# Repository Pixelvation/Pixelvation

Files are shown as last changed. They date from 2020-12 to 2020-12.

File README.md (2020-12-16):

**Pixelvation enables people to create high-quality LED art using open source tools**

This GitHub repository is the current home of Pixelvation and will be updated whenever there's some significant new development.  To get notified on significant new developments, set up an alert on new releases here, or follow [@PixelvationRGB on Twitter](https://twitter.com/PixelvationRgb).

I'll set up a forum or Discord server at some point, but for now, feel free to open a GitHub Issue, or post to [SmartMatrix Community](https://community.pixelmatix.com) if you have any questions or want to discuss anything.

## Open Source Early

I've released several open source products, where the open source files were published after the product was designed, manufactured, and at a distributor ready to purchase.  With my [latest crowdfunded product](https://www.crowdsupply.com/pixelmatix/smartled-shield-for-teensy-4) I realized how much time I had spent on marketing and logistics while prepping for and running the campaign - work I really dislike - relative to the creative and technical work that I really enjoy.  I also really enjoy sharing my projects and collaborating with other people, but releasing the product through a crowdfunding campaign delayed the start of fully sharing my project details and collaborating with other people by months.

With Pixelvation, I'm trying a new approach to sharing my projects: releasing projects as open source early on - well before I even have plans to release a project as a product - and making it easy for people to source the hardware themselves.  I'm designing my projects around components that are available from [JLCPCB's SMT Library](https://jlcpcb.com/parts) whenever possible, so if you want to try one of the hardware designs you just place an order with JLCPCB for 5+ pieces of assembled PCBs, and they'll be manufactured and shipped for a very reasonable price in under a week.

I'm releasing work-in-progress designs under a CC BY-NC-SA license.  Usually I don't release my designs with a "-NC" Non-Commercial license, and after the design is further along and ready for sale I'll change the license to CC BY-SA.  I'm conflicted about this and may change my mind later as designs released "-NC" aren't truly open source, but for now I'm being conservative and keeping the "-NC".

## Pixelvation Engine

The first tool in development now is the Pixelvation Engine, a small board dedicated to receiving a single stream of LED data via serial, and driving a lot of LEDs with that data.  The Engine will support driving HUB75 panels, or addressable LEDs.

Pixelvation Engine Overhead View

As input, Pixelvation Engine accepts APA102 data at up to 5MHz, with 1-bit serial (like an APA102 LED), or up to 8-bit parallel.  The 1-bit serial input and CLK are buffered to accept up to 5V signals, but the remaining 7-bits parallel data must be driven at 3.3V only.

Pixelvation Engine has 16 outputs buffered to 5V levels, and an extra 3.3V output.  The outputs are arranged around the pinout of a HUB75 panel, so the board can be plugged into a HUB75 panel directly.  To instead drive up to 16 channels of addressable LEDs, Pixelvation Engine needs to be plugged into a simple breakout board.  Generic breakout boards will be designed and released in the future, but you can also design your own project-specific breakout board with space for the Pixelvation Engine, and the form factor and LED connectors your project actually needs.

Pixelvation Engine is based around the ESP32, which has enough RAM, CPU power, and DMA functionality to deal with a lot of LED data, and some unique I2S peripherals that allow for receiving a fast stream of serial or parallel LED data as input, and setting up another stream of parallel LED data as output.

To program Pixelvation Engine you need a USB-Serial adapter.  This functionality was purposely left off the board to save space and cost, and ideally these features are only needed when setting up a project.  The programming pins on the input side were designed around the ESP-01 pinout, so cheap ESP-01 programmers can be used.  Specifically [this ESP-01 programmer](https://www.amazon.com/ESP-01S-Programmer-Adapter-Wireless-4-5-5-5V/dp/B07V556Q82) ([cheaper on Aliexpress](https://www.aliexpress.com/item/32882742790.html))  has the most functionality and is the easiest to use on its own, is widely available, and with a couple jumper wires added becomes even more functional.

Pixelvation Engine Programmer

### Status

Currently Pixelvation Engine has been tested driving HUB75 panels up to 64x64 pixels, with APA102 input sources from [Pixelblaze (V1-V3)](https://www.crowdsupply.com/hencke-technologies/pixelblaze-v3), [WLED's sound reactive fork](https://github.com/atuline/WLED/) compiled with APA102 output and running on an ESP32 Dev board, and a Fadecandy-inspired USB to APA102 output board currently in development.

Pixelvation Engine uses [SmartMatrix Library 4.0's](https://github.com/pixelmatix/SmartMatrix) ESP32 support for driving HUB75 panels, and is able to drive a 64x64 HUB75 panel with 36-bit color, at 240Hz.  It's possible to drive a 128x64 HUB75 panel with the same color settings, but it requires additional hardware outside the Pixelvation Engine (this is being prototyped now).

The addressable LED output functionality hasn't been tested yet.  

The I2S Input code has some room for improvement, as it's very inefficient with memory right now, and can't keep up with a 4MHz 1-bit serial input when driving a 64x64 pixel output, but this is fixable.

Pixelvation Engine Demo

[Click to watch demo video on Vimeo](https://vimeo.com/491391639/f8f3a9616e)

I ordered hardware version V0.1 assembled from [JLCPCB](https://jlcpcb.com) (10 pieces ~$70 plus shipping), and out of eight boards that I functionally tested, seven of them were working, and one has an undiagnosed problem.  The solder pad under the ESP32 should be using a [smaller squares for solder paste](https://twitter.com/GregDavill/status/1326309124565467136) instead of the one large square it's currently using, as the large square can lead to problems.  I don't plan on making any major changes to the pinout or functionality of the board at this point, but I may move to a 4-layer board, and shrink the board width by 0.1"/0.2" if possible.

### More Details

The hardware is posted in [Hardware/Pixelvation Engine](https://github.com/Pixelvation/Pixelvation/tree/master/Hardware/Pixelvation%20Engine), The Arduino sketch to drive HUB75 panels is [in a separate repo](https://github.com/Pixelvation/PixelvationEngine_HUB75) and more details are in  [the Wiki](https://github.com/Pixelvation/Pixelvation/wiki).

## About Pixelvation

I (Louis Beaudoin) created the open source [SmartMatrix Library](https://github.com/pixelmatix/SmartMatrix) and [SmartMatrix/SmartLED Shields](http://docs.pixelmatix.com/SmartMatrix/shieldref.html) for Teensy in 2014 under the name Pixelmatix and have been improving those projects ever since.  I thought a new brandname was appropriate for this series of new projects with a focus on both addressable LEDs and HUB75 LED matrix panels, and a focus on creating innovative tools for LED art.

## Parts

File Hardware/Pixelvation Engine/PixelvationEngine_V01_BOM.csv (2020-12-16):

Comment | Designator | Footprint | LCSC
10uF | C1,C3,C5 | Capacitor_SMD:C_0805_2012Metric | C15850
0.1uF | C2,C4,C6,C7,C8,C9 | Capacitor_SMD:C_0603_1608Metric | C14663
D | D1 | Diode_SMD:D_SOD-123F | C223608
LED | D2 | LED_SMD:LED_0805_2012Metric | C84256
Conn_01x04 | J1 | Connector_Harwin:Harwin_M20-89004xx_1x04_P2.54mm_Horizontal
Conn_02x10_Odd_Even | J11 | Connector_PinHeader_2.54mm:PinHeader_2x10_P2.54mm_Vertical_SMD
Conn_02x10_Odd_Even | J15 | Connector_PinSocket_2.54mm:PinSocket_2x10_P2.54mm_Vertical_SMD
Conn_02x10_Odd_Even | J16 | Connector_PinSocket_2.54mm:PinSocket_2x10_P2.54mm_Vertical
Conn_01x04 | J3 | Connector_PinHeader_2.54mm:PinHeader_1x04_P2.54mm_Vertical
Conn_02x10_Odd_Even | J6 | Connector_PinHeader_2.54mm:PinHeader_2x10_P2.54mm_Vertical
SolderJumper_2_Bridged | JP1,JP2 | Jumper:SolderJumper-2_P1.3mm_Bridged_Pad1.0x1.5mm
1k | R1 | Resistor_SMD:R_0603_1608Metric | C21190
0 | R2 | Resistor_SMD:R_0603_1608Metric | C21189
100 | R3 | Resistor_SMD:R_0603_1608Metric | C22775
10k | R4,R5 | Resistor_SMD:R_0603_1608Metric | C25804
74LVC2G17 | U1,U2 | Package_TO_SOT_SMD:SOT-363_SC-70-6 | C50714
AP2112K-3.3 | U3 | Package_TO_SOT_SMD:SOT-23-5 | C51118
ESP32-PICO-D4 | U4 | Package_DFN_QFN:QFN-48-1EP_7x7mm_P0.5mm_EP5.45x5.45mm | C193707
74HC245 | U5,U6 | Package_SO:TSSOP-20_4.4x6.5mm_P0.65mm | C173388

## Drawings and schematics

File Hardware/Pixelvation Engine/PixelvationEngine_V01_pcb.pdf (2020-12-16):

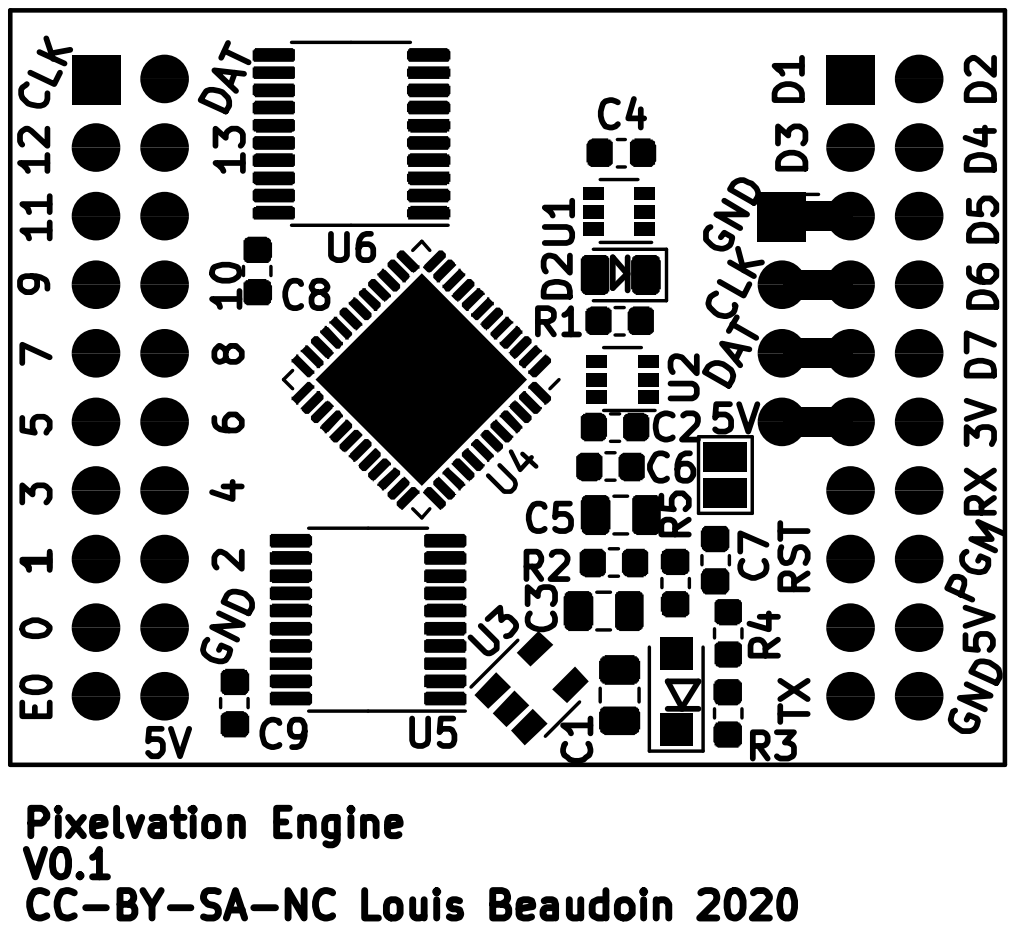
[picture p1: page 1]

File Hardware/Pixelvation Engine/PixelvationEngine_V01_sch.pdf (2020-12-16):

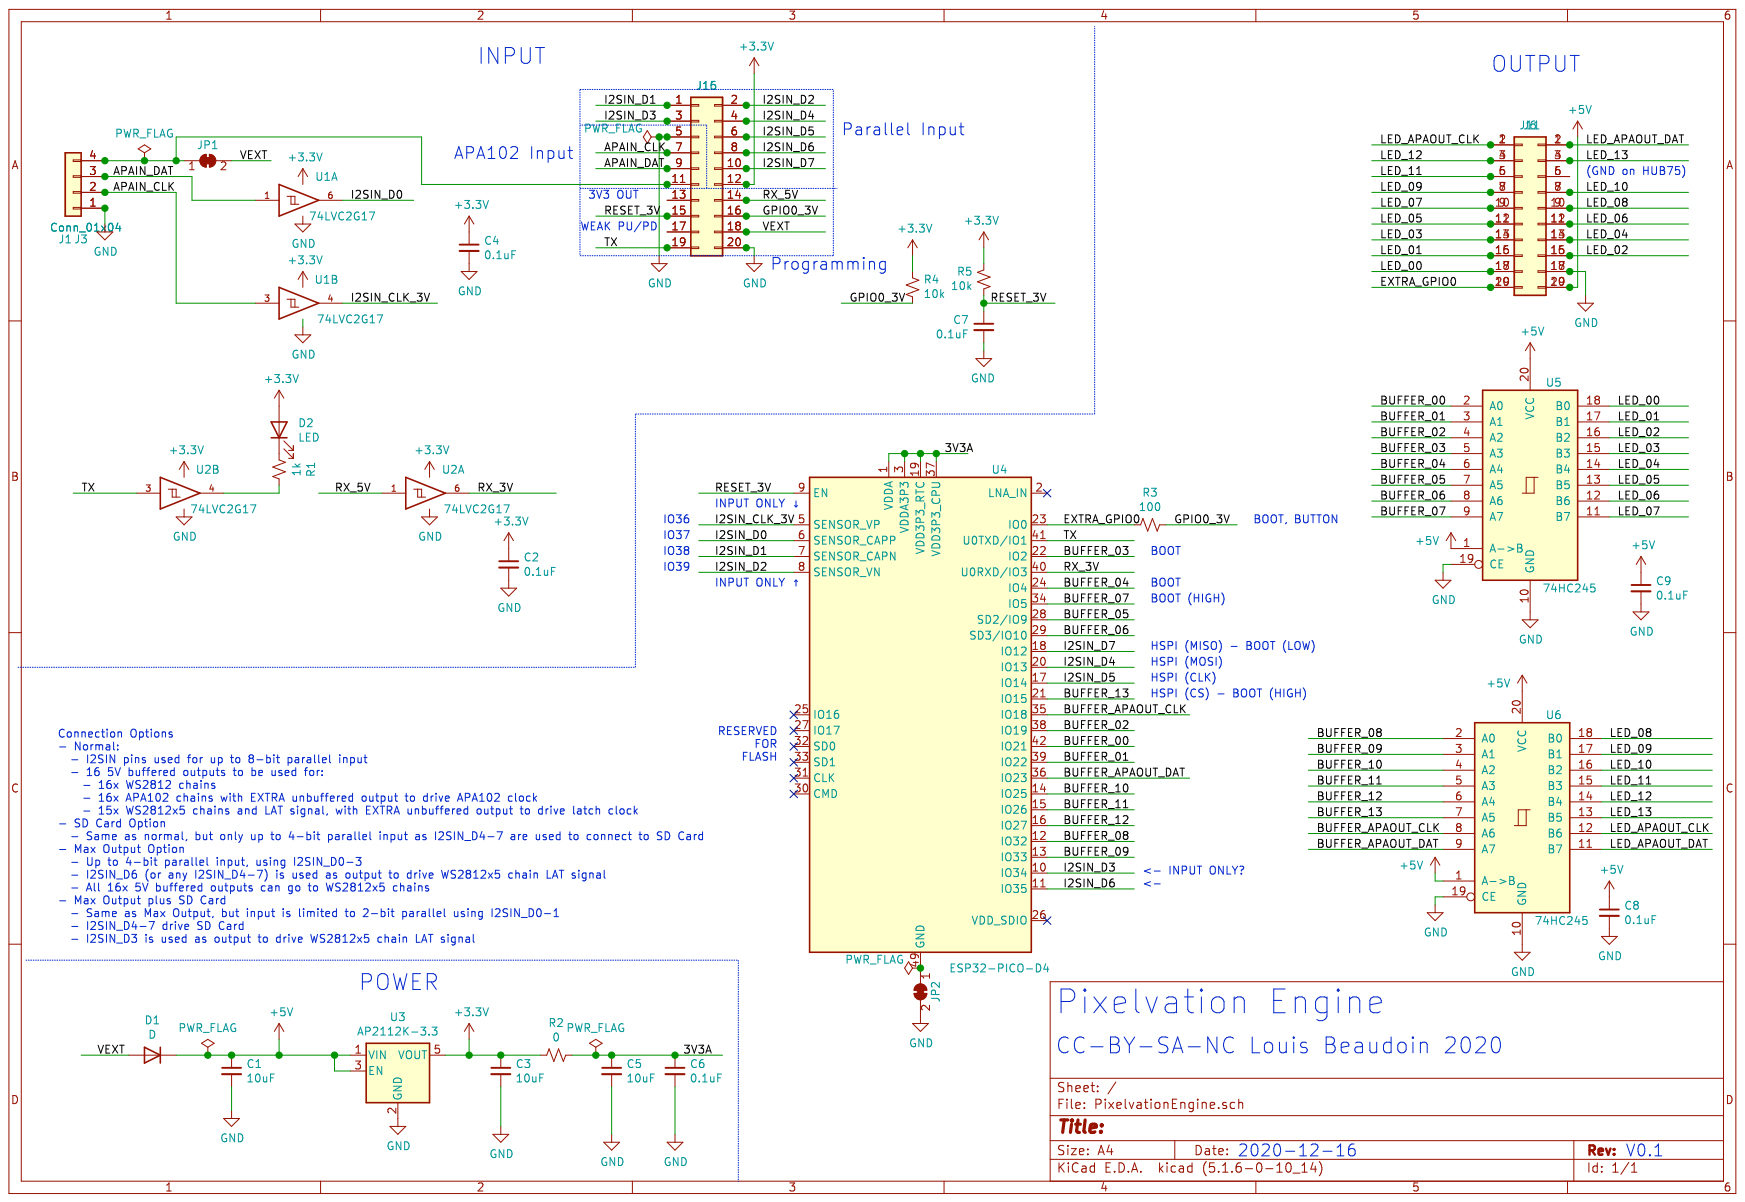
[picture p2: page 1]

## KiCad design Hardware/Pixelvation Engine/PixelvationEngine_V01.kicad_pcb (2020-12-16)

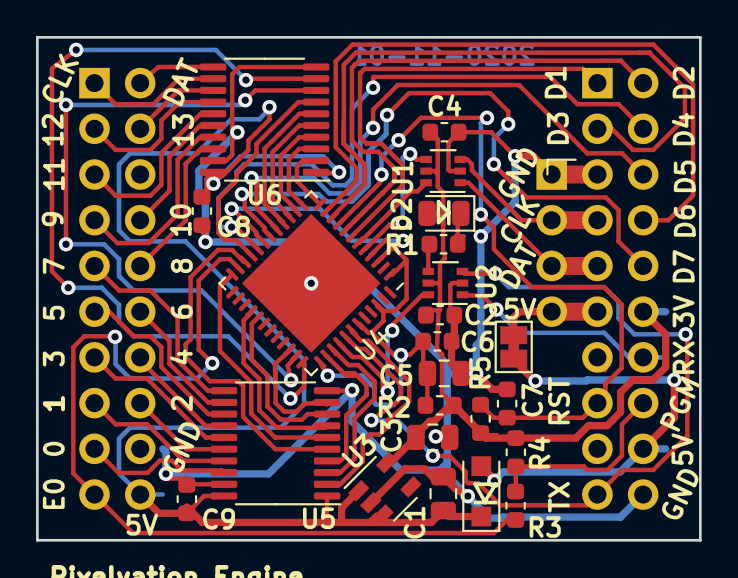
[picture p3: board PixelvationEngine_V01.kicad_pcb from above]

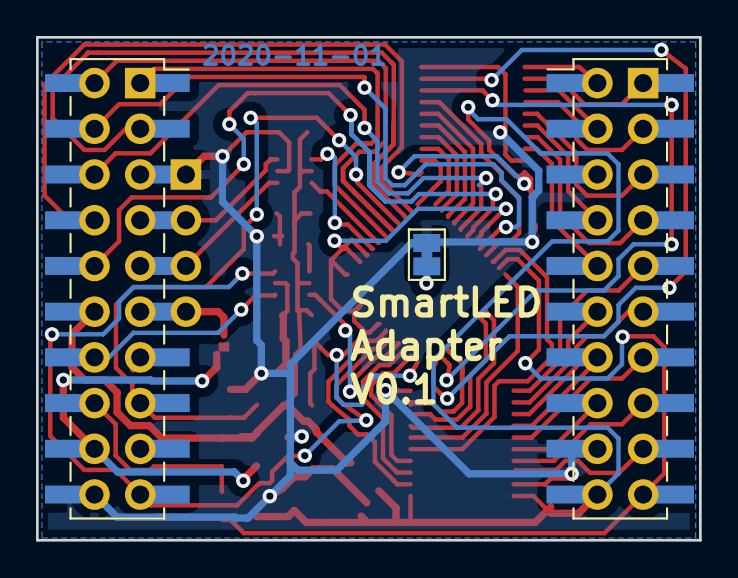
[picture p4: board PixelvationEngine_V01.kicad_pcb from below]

Board: 2 copper layers, 36.8 x 27.9 mm, 30 parts (4 on the bottom side), 61 nets.

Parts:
C1, C3, C5: 10uF; C_0805_2012Metric
C2, C4, C6, C7, C8, C9: 0.1uF; C_0603_1608Metric
D1: D; D_SOD-123F
D2: LED; LED_0805_2012Metric
J1: Conn_01x04; Harwin_M20-89004xx_1x04_P2.54mm_Horizontal
J3: Conn_01x04; PinHeader_1x04_P2.54mm_Vertical
J6: Conn_02x10_Odd_Even; PinHeader_2x10_P2.54mm_Vertical
J11: Conn_02x10_Odd_Even; PinHeader_2x10_P2.54mm_Vertical_SMD
J15: Conn_02x10_Odd_Even; PinSocket_2x10_P2.54mm_Vertical_SMD
J16: Conn_02x10_Odd_Even; PinSocket_2x10_P2.54mm_Vertical
JP1, JP2: SolderJumper_2_Bridged; SolderJumper-2_P1.3mm_Bridged_Pad1.0x1.5mm
R1: 1k; R_0603_1608Metric
R2: 0; R_0603_1608Metric
R3: 100; R_0603_1608Metric
R4, R5: 10k; R_0603_1608Metric
U1, U2: 74LVC2G17; SOT-363_SC-70-6
U3: AP2112K-3.3; SOT-23-5
U4: ESP32-PICO-D4; QFN-48-1EP_7x7mm_P0.5mm_EP5.45x5.45mm
U5, U6: 74HC245; TSSOP-20_4.4x6.5mm_P0.65mm

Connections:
+3V3: C2.1, C3.1, C4.1, D2.2, J15.12, J16.12, R2.2, R4.2, R5.2, U1.5, U2.5, U3.5
+5V: C1.1, C8.1, C9.1, D1.1, J6.20, J11.19, U3.1, U3.3, U5.1, U5.20, U6.1, U6.20
/3V3A: C5.1, C6.1, R2.1, U4.1, U4.3, U4.4, U4.19, U4.37, U4.43, U4.46
/APAIN_CLK: J1.2, J3.2, J15.7, J16.7, U1.3
/APAIN_DAT: J1.3, J3.3, J15.9, J16.9, U1.1
/BUFFER_00: U4.42, U5.2
/BUFFER_01: U4.39, U5.3
/BUFFER_02: U4.38, U5.4
/BUFFER_03: U4.22, U5.5
/BUFFER_04: U4.24, U5.6
/BUFFER_05: U4.28, U5.7
/BUFFER_06: U4.29, U5.8
/BUFFER_07: U4.34, U5.9
/BUFFER_08: U4.12, U6.2
/BUFFER_09: U4.13, U6.3
/BUFFER_10: U4.14, U6.4
/BUFFER_11: U4.15, U6.5
/BUFFER_12: U4.16, U6.6
/BUFFER_13: U4.21, U6.7
/BUFFER_APAOUT_CLK: U4.35, U6.8
/BUFFER_APAOUT_DAT: U4.36, U6.9
/EXTRA_GPIO0: J6.19, J11.20, R3.2, U4.23
/GPIO0_3V: J15.16, J16.16, R3.1, R4.1
/I2SIN_CLK_3V: U1.4, U4.5
/I2SIN_D0: U1.6, U4.6
/I2SIN_D1: J15.1, J16.1, U4.7
/I2SIN_D2: J15.2, J16.2, U4.8
/I2SIN_D3: J15.3, J16.3, U4.10
/I2SIN_D4: J15.4, J16.4, U4.20
/I2SIN_D5: J15.6, J16.6, U4.17
/I2SIN_D6: J15.8, J16.8, U4.11
/I2SIN_D7: J15.10, J16.10, U4.18
/LED_00: J6.17, J11.18, U5.18
/LED_01: J6.15, J11.16, U5.17
/LED_02: J6.16, J11.15, U5.16
/LED_03: J6.13, J11.14, U5.15
/LED_04: J6.14, J11.13, U5.14
/LED_05: J6.11, J11.12, U5.13
/LED_06: J6.12, J11.11, U5.12
/LED_07: J6.9, J11.10, U5.11
/LED_08: J6.10, J11.9, U6.18
/LED_09: J6.7, J11.8, U6.17
/LED_10: J6.8, J11.7, U6.16
/LED_11: J6.5, J11.6, U6.15
/LED_12: J6.3, J11.4, U6.14
/LED_13: J6.4, J11.3, U6.13
/LED_APAOUT_CLK: J6.1, J11.2, U6.12
/LED_APAOUT_DAT: J6.2, J11.1, U6.11
/RESET_3V: C7.1, J15.15, J16.15, R5.1, U4.9
/RX_3V: U2.6, U4.40
/RX_5V: J15.14, J16.14, U2.1
/TX: J15.19, J16.19, U2.3, U4.41
/VEXT: D1.2, J15.18, J16.18, JP1.2
GND: C1.2, C2.2, C3.2, C4.2, C5.2, C6.2, C7.2, C8.2, C9.2, J1.1, J3.1, J6.18, J11.17, J15.5, J15.20, J16.5, J16.20, JP2.2, U1.2, U2.2, U3.2, U5.10, U5.19, U6.10, U6.19
unnamed: D2.1, R1.2
unnamed: J1.4, J3.4, J15.11, J16.11, JP1.1
unnamed: J6.6, J11.5
unnamed: J15.13, J16.13
unnamed: J15.17, J16.17
unnamed: JP2.1, U4.49
unnamed: R1.1, U2.4

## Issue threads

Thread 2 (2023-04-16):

Tindle Store?

mermelmadness, 2023-04-16:
I acquired one of these from a friend who got them from PCBWay and had extras.  Love it.  I want to get 5 more but he's not responding to my inquiries.  Do you you have a Tindle store?  I have no experience ordering from a PCB maker.  I've sent companies the gerber files but they keep asking for more information for the ICs and I don't know enough to tell them anything useful.  I'd love to buy them preassembled.  Willing to pay a good amount for them.

mermelmadness, 2023-04-17:
I did.  He's who I got the original from.  He did say he ordered a bunch more and was working on the SMD himself, but he's been unresponsive for the last few weeks.  I don't want to keep pestering him in case he's going through some personal stuff that's keeping him away, so I looked into having them printed myself.

mermelmadness, 2023-05-10:
I've been trying to submit the gerber, BOM, and CPL files to PCB printers, but either they don't process correctly in their system or they don't have all the components required.  Soren is still unresponsive, so I'm currently stuck.  Really want more Pixelvation boards.

embedded-creations, 2023-05-10:
Did you try JLCPCB? That’s where I ordered from and they’re most likely to have all the parts

mermelmadness, 2023-05-10:
JCLPCB was the first place I tried.  They don't recognize one of the components from the BOM and don't have enough of another.  When searching for it, I found a similar part, but it seems to be out of stock.
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

mermelmadness, 2023-05-11:
Apologies, but I haven't had any luck with any PCB Printing service.  They all say that the BOM and POS file are incomplete with part info.  I'm sorry that I don't know enough about this to handle this myself.  I just really wanted to buy 5 of the boards to build a 3x2 information panel for my office (192x128).

mermelmadness, 2023-05-25:
@embedded-creations ok, I got them.  Time to do some soldering.  Thank you for your help and permission to print these for myself.  Keep an eye on the WLED Discord for project updates in the coming weeks.
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

embedded-creations, 2023-05-25:
Sweet, thanks for the update. Any advice for others trying to order? Did you find a substitute for the missing part?

mermelmadness, 2023-05-25:
From what I went through, the BOM lists the pinholes as parts, so they will come up as not found when you submit it.

The out of stock part was C223608
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

I replaced it with C8598
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

I had to go to a forum to ask what replacement parts would be viable and the mentioned the LCSC product numbers.

Also, the original rendering of the assembled board had the voltage regulator offset by 90 degrees.
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

Thankfully their engineers know what they're doing, so they corrected for it.
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

mermelmadness, 2023-05-25:
BTW, this issue can be closed.

Closed 2023-05-25.

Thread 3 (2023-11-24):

Love This Board

mermelmadness, 2023-11-24:
Not an issue, just wanted to say thanks for designing this and allowing free use for personal projects.  I printed a bunch of these from JLCPCB and built this huge LED Matrix information panel made from 6 64x64 HUB75 panels.  Powered by WLED and data fed from Home Assistant, everything you see updates in real time.

Forgive my novice soldering, been doing it less than a year.  Also, I love it so much I had it professionally framed.

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

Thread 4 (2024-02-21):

Error on JLCPCB

tfm3rd, 2024-02-21:
asked for BOM and  CPL file  the i uploaded the BOM returns 5 Not Matched Parts.  I assume the CPL is the V01-top-pos.csv

tfm3rd, 2024-02-21:
Comment | Footprint | DESIGNATOR | No matches found

Conn_01x04 | Connector_Harwin:Harwin_M20-89004xx_1x04_P2.54mm_Horizontal | J1 | No matches found

Conn_02x10_Odd_Even | Connector_PinSocket_2.54mm:PinSocket_2x10_P2.54mm_Vertical_SMD | J15 | No matches found
 
Conn_02x10_Odd_Even | Connector_PinSocket_2.54mm:PinSocket_2x10_P2.54mm_Vertical | J16 | No matches found

SolderJumper_2_Bridged | Jumper:SolderJumper-2_P1.3mm_Bridged_Pad1.0x1.5mm

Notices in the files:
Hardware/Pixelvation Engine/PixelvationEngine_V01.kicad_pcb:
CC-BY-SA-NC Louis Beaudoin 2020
